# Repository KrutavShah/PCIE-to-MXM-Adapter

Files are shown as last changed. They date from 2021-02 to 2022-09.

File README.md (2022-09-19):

# PCIE to MXM Adapter
This adapter/card allows you to plug an MXM 3.0/3.1 graphics card into a desktop PCI Express port.
There's multiple use cases for this, including MXM card testing, repair, basic computer use, gaming, light workstation use, and more.
This adapter design has been made publicly viewable for educational purposes. 
I made this desicion because of the very high prices that these MXM adapters usually go for online, 
as well as to allow the general public to understand how MXM cards can be interfaced 
with computers to function.
As always, feel free to create issues on this repository and contribute to the project.

Picture of the PCIE x1 to MXM Adapter.

## Current Progress

**Early Prototype:**

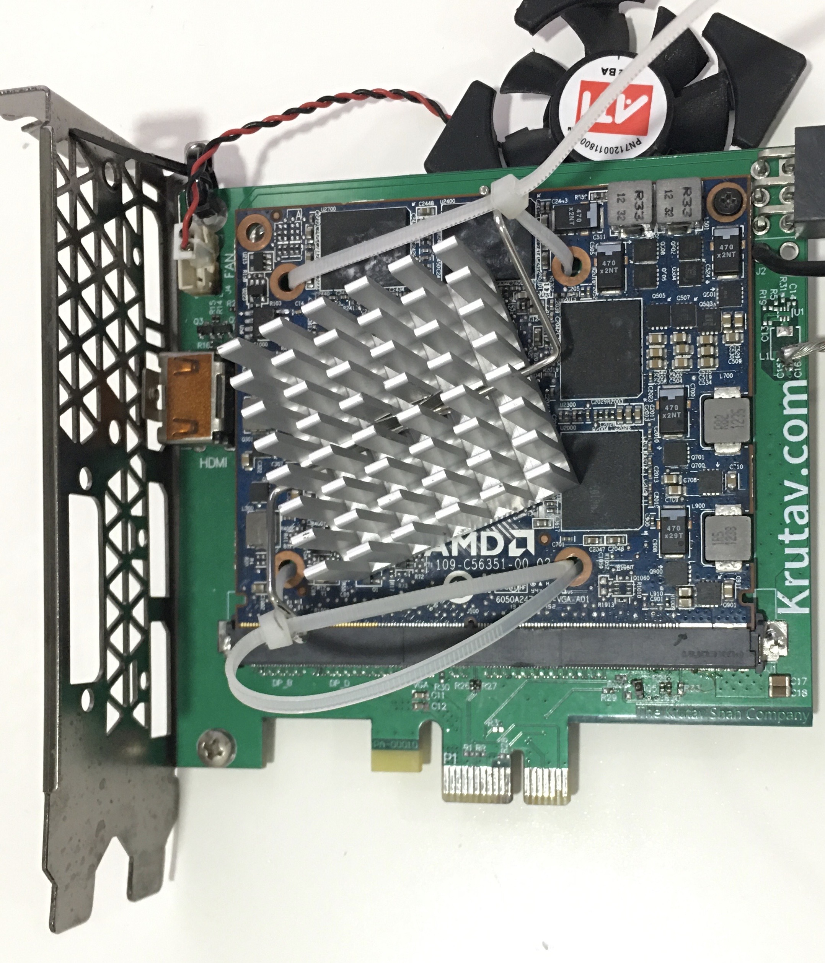
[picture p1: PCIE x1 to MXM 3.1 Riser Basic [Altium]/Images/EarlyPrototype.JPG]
Picture of an early prototype.


What Works:

- HDMI port can output, only version 1.4 bandwidths were tested.
- PCI-e Gen 2 link speed.
- MXM Type-A card fully functional on PCI-e x1 slot power.
- Boot screen and BIOS are accessible through it.
- Can play games and use workstation software.

What Might Not Work:

- PWM fan speed, this feature is dependent on the MXM card's manufacturer including support for it.
- HDMI may show up as a DVI port on some combination of cards and monitors. Further testing will be necessary.

Other features have not been tested due to a lack of MXM cards to test with, such as HDMI Version 2.0 bandwidth. I only have one card, the AMD FirePro M4000, which is an old card and not the best candidate for testing.

**Note:** this is the first prototype and much has changed since it was produced.

## Licensing information
The work of this project is property of Krutav Shah, &copy; 2022. 
Reproduction is not allowed. Commercial use is prohibited.

Some of the material here, such as the footprints in the parts library are the works of various providers such as Molex LLC. Those organizations hold the rights to those resources that have been used in this project.

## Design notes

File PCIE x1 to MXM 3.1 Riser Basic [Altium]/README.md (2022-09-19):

# PCIE x1 to MXM 3.0 Adapter

This adapter card is the most basic one, and includes one HDMI output.
This card is designed to be compact and takes up 100x100mm for inexpensive
PCB fabrication. It has a total of one PCI-e lane and contains basic features.

## What can I use this for?

This card is cheap and small, making it great for testing out and flashing MXM Video Cards.
You can also use it as a video adapter in a machine that needs one, like a server or theater PC.
This card will fit in a full height slot, but not a half height slot.

## Technical Specification

- MXM Type: Version 3 Type A card (Size B may work but there may not be enough power)
- HDMI: 1 Type A port (Should support up to HDMI 2.0)
- Power: Maximum of 25W over PCIE connector as per specification, but actual maximum value may be more or less depending on the motherboard.
- PCB: 4 Layer, 1.6mm Thick, 100x100mm in size. (For JLCPCB Fabrication, use Stackup JLC-2313)

## Help out the project!

Have any issues, comments, or concerns? 
Feel free to create a new issue on GitHub and we can take a look at it.
This product was made in KiCAD EDA originally, but has since moved to Altium Designer.
This project is open source, so contributions are welcome!

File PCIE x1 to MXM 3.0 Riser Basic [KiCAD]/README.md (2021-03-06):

# PCIE x1 to MXM 3.0 Adapter

This adapter card is the most basic one, and includes (1) HDMI output, 
a VGA dummy toggle, and an external 6 pin power connector.
This card is designed to be compact and fit within 100x100mm for inexpensive
PCB fabrication. It has a total of (1) PCIE lane and contains basic features.

## What can I use this for?

This card is cheap and small, making it great for testing out and flashing MXM Video Cards.
You can also use it as a video adapter in a machine that needs one, like a server or theater PC.
This card will fit in a full height slot, but not half height.

## Technical Specification

- MXM Type: 3.0 Type A card (Size B may work with the addition of an external power connector.
- HDMI: 1 Type A port (1.4 compatible)
- VGA: 1 virtual dummy adapter. Turn the dummy toggle to the ON position to activate.
- Power: Maximum of 25W over PCIE connector, but actual maximum value may be less. 
6-Pin power connector is available to increase maximum power throughput.
- PCB: 2 Layer, 1.6mm Thick, Fits within 100x100mm size.

## Help out the project!

Have any issues, comments, or concerns? 
Feel free to create a new issue on GitHub and we can take a look at it.
This whole assembly was made in KiCAD EDA, a free and open source tool.
All of these projects are open source, so contributions are welcome!

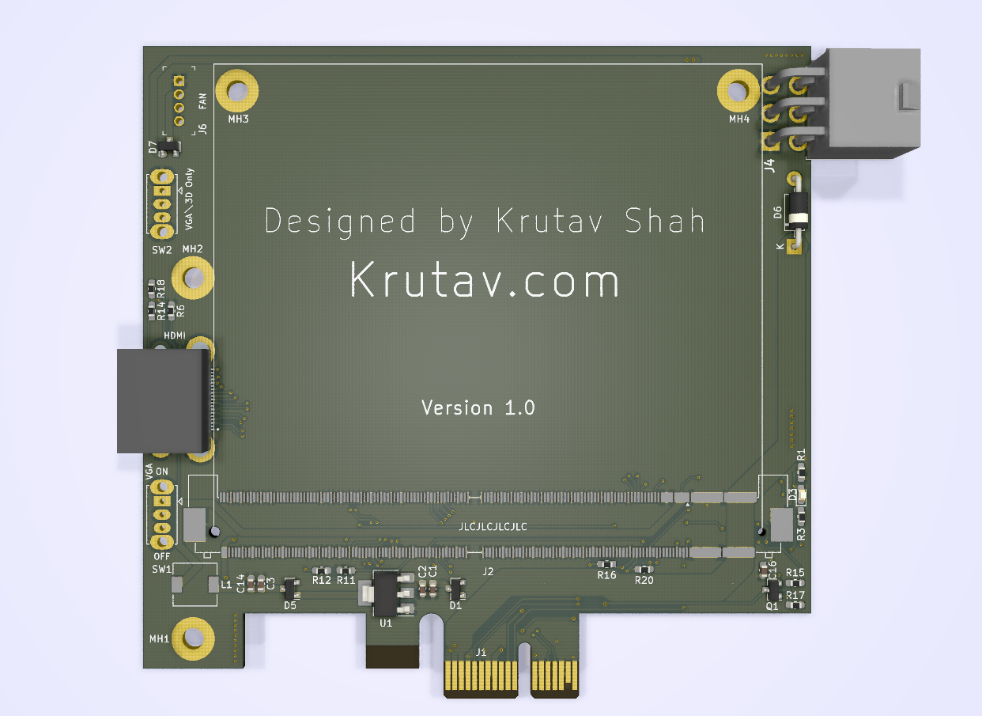
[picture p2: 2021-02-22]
PCIE x1 to MXM 3.0 Riser Basic [KiCAD]/Images/Front1.PNG

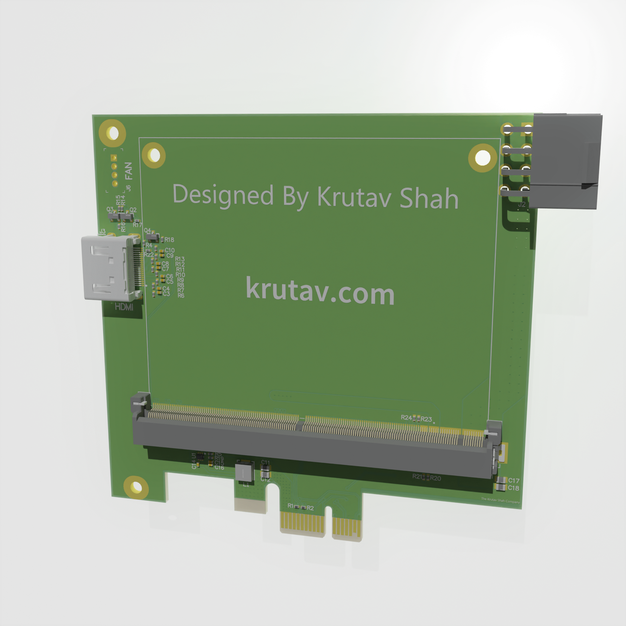
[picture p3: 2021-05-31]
PCIE x1 to MXM 3.1 Riser Basic [Altium]/Images/MXMRiserBasicRender1.png

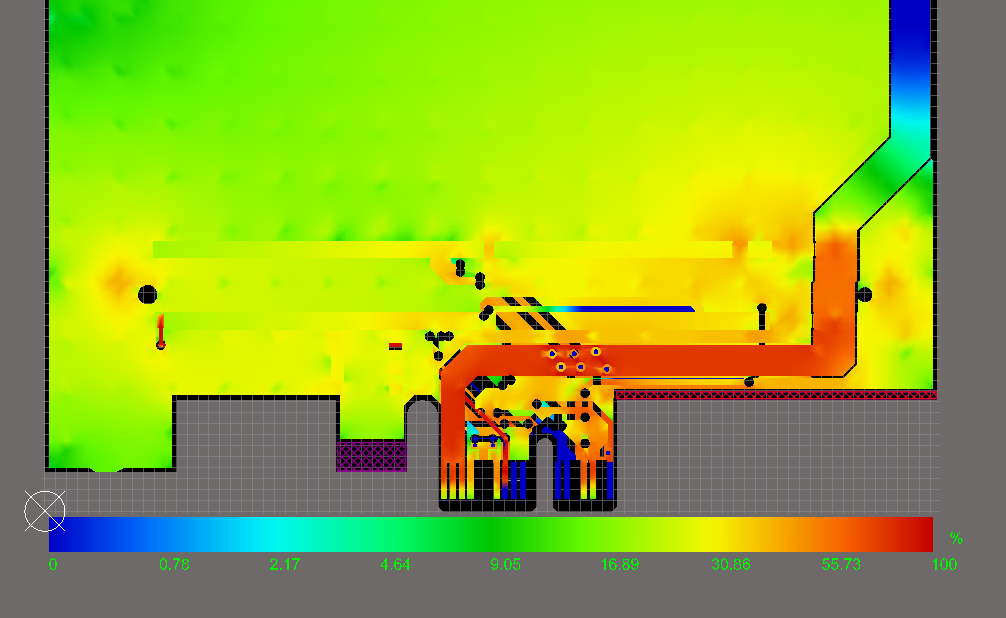
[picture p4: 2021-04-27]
PCIE x1 to MXM 3.1 Riser Basic [Altium]/Images/PDNSimulation.PNG

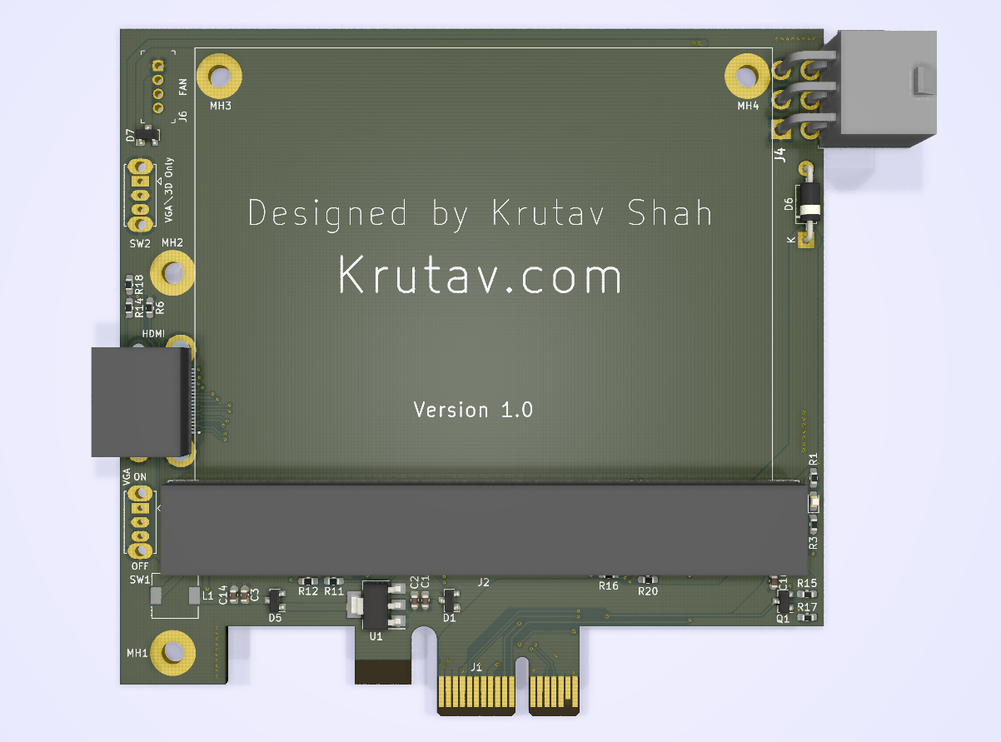
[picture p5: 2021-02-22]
PCIE x1 to MXM 3.0 Riser Basic [KiCAD]/Images/Front2.PNG

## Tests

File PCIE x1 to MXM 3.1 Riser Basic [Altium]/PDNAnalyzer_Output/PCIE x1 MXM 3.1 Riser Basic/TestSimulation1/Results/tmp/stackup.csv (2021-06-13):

layername
TOPSOLDER
TOPLAYER
SUBSTRATE-1
INTERNALPLANE1
SUBSTRATE-2
INTERNALPLANE2
SUBSTRATE-3
BOTTOMLAYER
BOTTOMSOLDER

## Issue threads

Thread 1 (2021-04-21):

Adapter design discussion

chraac, 2021-04-21:
Looks the PCB files in altium project of both x1 and x16 was not properly updated, are they still under development?

chraac, 2021-04-21:
Also the Altium Designer show that the footprint of PCIeX1 was not found, just curious if it missing something when convert from KiCAD project

KrutavShah, 2021-04-21:
Yes, it is still under development. Currently I am working on other projects so time is limited.

The goal is to transition from KiCAD to Altium, so I’m in the process of redesigning each board in Altium to gain more advanced features necessary for designing the board with high speed signals and relatively good design standards.

chraac, 2021-04-21:
> Yes, it is still under development. Currently I am working on other projects so time is limited.
>
> The goal is to transition from KiCAD to Altium, so I’m in the process of redesigning each board in Altium to gain more advanced features necessary for designing the board with high speed signals and relatively good design standards.

Thanks for quick reply, I think I can help to do some developing or testing, I have a spare MXM graphics card and can test the PCB if it work.

KrutavShah, 2021-04-21:
Thanks for the offer, I do have an MXM card available too, so the only issue is that it will take a few weeks to actually manufacture the adapter.

Since the project is still in development, it will take some time before its fully ready for manufacturing. If you want to help contribute to designing and/or validation, feel free to do so!

chraac, 2021-04-25:
@KrutavShah, anyway, I think you should remove the ```History``` folder under every altium project, it's altium zip cache, unable to diff by version control. Or init the [Git LFS](https://git-lfs.github.com/) to manage it more efficiently.

KrutavShah, 2021-04-25:
I will add .zip files to the gitignore in that case, thanks for the suggestion. I hope to commit the work I have been working on for the past few days to this repository today.

chraac, 2021-04-26:
From the [MXM spec v3.1, page 36](https://www.module-store.de/media/pdf/d9/a4/43/MXM_Specification_v31_r10.pdf), the ```PWR_LEVEL``` pin define 1 as full power, and should pull-up to 3.3v with 100KΩ resistor, I think we should follow the spec.

KrutavShah, 2021-04-26:
So the last commit that I made yesterday was simply to route PCIE. Stitching vias and MXM specific pull up and pull down resistors will come next in the next few days. I have all the MXM design papers except for the MXM System Design Guide which is perhaps the most useful.

The things that I’m not sure about how to implement is actually the PWR_EN and TH_OVERT# signals. There may also be some more signals to consider later on that I’m not entirely sure on. For example, newer cards don’t support TMDS/LVDS which means HDMI needs to be connected to DisplayPort.

chraac, 2021-04-27:
I think it will be relative easy if we only implement the ```PWR_EN```, from the spec, we can pull-up the ```PWR_EN``` when all 12v/5v/3.3v are ready, and then the module will give us a ```PWR_GOOD``` within 90ms to enable the signal input.
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

And the ```TH_OVERT#``` is for over heat shutdown, IMHO, maybe we can just pull-up to 3.3v, leave it for later implementation since we are not on a budget of cooler.

KrutavShah, 2021-04-27:
> from the spec, we can pull-up the PWR_EN when all 12v/5v/3.3v are ready

But how would you? The idea I had previously is to branch PWR_EN off +5V with a voltage divider (2 resistors) and the reason being that 5V is created the last, and then using the resistor divider turns the 5V into 3.3V. IIRC, PWR_GOOD is not a required signal and can therefore be omitted.

> And the TH_OVERT# is for over heat shutdown, IMHO, maybe we can just pull-up to 3.3v

We actually should keep TH_OVERT# because it's a required signal, and while the adapters are supposed to be cheap, I would not remove this important feature just to save a fraction of a dollar. So how do we implement this? One possible solution is with a transistor. If TH_OVERT# is asserted, the transistor will open and send 3.3V directly to PCIE_RESET#. Let me know if this will work, or if you have any comments on the solution.

chraac, 2021-05-03:
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

Use 2 resistor as voltage divider should be ok since the resistance of PWR_EN to GND is far more bigger than our resistor's. But I had to go to PCIR spec to find which one of 12/5/3.3 come first.

KrutavShah, 2021-05-03:
> Use 2 resistor as voltage divider should be ok since the resistance of PWR_EN to GND is far more bigger than our resistor's. But I had to go to PCIR spec to find which one of 12/5/3.3 come first.

This is already in the KiCAD design file and will be added to the Altium file when I have time. What I don't understand is how much 5V current is actually needed. MXM specifications says 2.5 Amps is required, but the AMS1117 can only provide 1 Amp. There are buck converters on the market capable of 3 Amps, but they are from companies like Anpec which don't sell on DigiKey or Mouser. I did find one of them on LCSC for $2 but it will take a long time to ship here.

In addition, I need to know how TH_OVERT# will be implemented because it has to assert a PCIE Reset, but how is not known.

chraac, 2021-05-04:
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

I did find a 12v to 5v buck converter from TI website - [LM2596 SIMPLE SWITCHER® Power Converter 150-kHz
3-A Step-Down Voltage Regulator](https://www.ti.com/lit/ds/symlink/lm2596.pdf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), and the example circuit look very simple:
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
Just 2 capacitor, 1 diode and 1 inductor, no extra MOSFET, it's fully integrated.

KrutavShah, 2021-05-04:
The LM2596 is huge, and making space for it on such a small board doesn't make as much sense. There are 3A 5V converters like those from Anpec and uPI Group that fit in a very small SOP-8 package and are designed to be used in these electronics. Though they are not sold on sites like DigiKey, so I have to find a good similar alternative.

chraac, 2021-05-07:
> The LM2596 is huge, and making space for it on such a small board doesn't make as much sense. There are 3A 5V converters like those from Anpec and uPI Group that fit in a very small SOP-8 package and are designed to be used in these electronics. Though they are not sold on sites like DigiKey, so I have to find a good similar alternative.

I think 1 amp from AMS1117 is not sufficient for recent GPU, I also doubt that the SOP-8 buck convertor is can provide up to 3 amps output. I gonna find another solution for 12v to 5v on DigiKey.

KrutavShah, 2021-05-07:
Actually, in addition to the 2.5 Amps for the GPU MXM card, you will notice on most normal desktop graphics cards that there is a separate AMS1117-5.0 just for powering the HDMI and DVI ports. Since we are using a 3A buck converter, that may be able to spare some current for the display outputs.

https://fscdn.rohm.com/en/products/databook/datasheet/ic/power/switching_regulator/bd9d321efj-e.pdf
Take a look at this one I have found for a reasonable price.

chraac, 2021-05-08:
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

Good to see a sop8 convertor solution for 12v to 5v in such small package. I know that the recent desktop graphic card rely on 12v far more than 5v for supplying GPU and MEM, but, IMHO, the mobile gpu may different since the battery maybe less than 12v, and the peripherals may using 5v usually than 12v（fan and others）.

KrutavShah, 2021-05-08:
>I know that the recent desktop graphic card rely on 12v far more than 5v for supplying GPU and MEM, but, IMHO, the mobile gpu may different since the battery maybe less than 12v, and the peripherals may using 5v usually than 12v(fan and others).

There's a lot more under the hood when it comes to desktop GPUs, as they usually have multiple 5V sources and possibly even multiple 3.3V sources according to the schematics. As far as MXM is concerned, 2.5A should be enough to drive the GPU power controller, clock, and a couple other components. Each HDMI port needs about 50-60 mA @ 5V, and DisplayPort uses 3.3V@500 mA.

In the case of this basic design, 3 Amps will be just fine. There is a difference between switching buck converters/voltage regulators and LDOs, as the more common switching chips used here need external circuitry like an inductor, capacitors, and resistors. LDOs (Low dropout regulators) don't need nearly as many extra passive components IIRC, so I am trying to find one of those instead.

I've worked on the design a fair bit, but I can't push it yet until the schematics are corrected, so I hope to get that done soon.

KrutavShah, 2021-05-08:
Moved to the discussions tab.

Closed 2021-05-08.

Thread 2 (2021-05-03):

For purchase anywhere?

nmjohnson, 2021-05-03:
Are you or any vendor making these?

KrutavShah, 2021-05-03:
The design is not complete yet, and is not ready for manufacture.

The goal is to make it so the PCB will only cost a few dollars, or in other words, be very low-cost. It's only for personal use, not commercial, which is why this open-source design is provided to the consumer only for the purpose of finding a manufacturing service to manufacture one of these for personal use.

JLCPCB offers PCB fabrication for a really low cost, so that may be a service you might consider using when going to get this design fabricated.

nmjohnson, 2021-05-03:
I understand. Well whenever it's ready I would like to test it out so let me know!

Tretecou, 2022-02-04:
Hey there, I would like to ask if the current design supports a graphics card that can draw up to 90W - such as the tesla p6.
Thanks in advance!

Tretecou, 2022-02-05:
>

Thanks a lot! I will be waiting for it - one more question, whats the best place and way to learn electronics engineering, electronics repair on a semi professional level without actually attending a dedicated school for this topic? Since im pretty young to actually go to a school like this and ive also missed my opportunity to visit a low level engineering school, are there other ways? I sometimes cant find enough time or get easily distracted when learning something. Plus i dont know what to learn exactly, ive missed a lot of beginner knowledge by not going to the type of school.
Thanks a lot for any kind of answer!
Happy designing :D

KrutavShah, 2022-07-13:
> Thanks a lot! I will be waiting for it - one more question, whats the best place and way to learn electronics engineering, electronics repair on a semi professional level without actually attending a dedicated school for this topic? Since im pretty young to actually go to a school like this and ive also missed my opportunity to visit a low level engineering school, are there other ways? I sometimes cant find enough time or get easily distracted when learning something. Plus i dont know what to learn exactly, ive missed a lot of beginner knowledge by not going to the type of school.
> Thanks a lot for any kind of answer!
> Happy designing :D

Hi, I apologize for not responding. If you’re still interested, I actually started this project without much knowledge of electronics design. Essentially, I had an idea, and knowledge of electronics repair and some of the basic concepts. The idea for this project came up when I had an MXM GPU but no way to actually use it. I want to emphasize that this project was not easy by any means, and I learned a lot just by doing. Concepts like signal integrity become especially important when dealing with high speed signals, so for issues like these, I read articles and watched videos that show proper practices and how to use tools within the design software to achieve the desired result. This project was started over a year ago and has experienced many major revisions as I made important realizations with each one.

I’m glad to hear that you’re interested in learning electronics, and you too can certainly begin the journey of learning how to design your own electronics products as you go. It won’t be particularly easy, but you’ll learn more with each revision and gain important experience. My best advice is to come up with what you want to make, making sure that your idea is still feasible. Once you have an idea in mind, you can draw it out, write about it, and begin your research. If you’ve made it to that point, you can begin designing in various different CAD software like KiCAD.

Hope this helps you, and thank you for asking!

Tretecou, 2022-07-13:
no biggie

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

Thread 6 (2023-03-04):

PCIe x16 version

renne, 2023-03-04:
This is a great project! :+1:

PCIe x1 is quite a bottleneck for modern GPUs.
I suggest to upgrade the PCB to PCIe x16 like the [EGX-MXM-AD](https://www.adlinktech.com/Products/Embedded_Graphics/embedded-graphics-solutions/EGX-MXM-AD?lang=en) or the [Eurocom](https://eurocom.com/ec/multigpu()multiGPU) riser cards.

KrutavShah, 2023-03-04:
I agree, x1 is definitely a bottleneck from my testing. I do have an x16 design that is missing a few components here and there, so not complete, but I have not released that here because I feel like the interest in this project has fallen away after a while of not being updated.

If this x16 version (with 4x DisplayPorts) is something you still want to see, I would be inclined against adding all the design files here, simply because the ones for x1 design already available here have been copied by others without credit. I feel like it may not be worth bothering with as a result. I am, however, open to considering this again in the future if there is enough interest. Here is what the design currently looks like:
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

renne, 2023-03-05:
Great! :+1:
Please make sure the positions of the video ports match an easily available bezel.
It would also be great to have an universal PCB layout which allows to solder HDMI or Displayport sockets at will.

KrutavShah, 2023-03-05:
The PCB layout matches Nvidia's 10/20 series PCI brackets, so you could get one of those and the ports should line up exactly. On the front page of this repository, I have one of these GTX 1060 brackets installed on my prototype which you take a look at if you'd like. Quadro brackets should also work. I do not think AMD brackets line up with the ports, though.

RansomScientist, 2023-03-12:
> I agree, x1 is definitely a bottleneck from my testing. I do have an x16 design that is missing a few components here and there, so not complete, but I have not released that here because I feel like the interest in this project has fallen away after a while of not being updated.
>
> If this x16 version (with 4x DisplayPorts/3x DP + 1x HDMI) is something you still want to see, I would be inclined against adding all the design files here, simply because the ones for x1 design already available here have been copied by others without credit. I feel like it may not be worth bothering with as a result. I am, however, open to considering this again in the future if there is enough interest. Here is what the design currently looks like: 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

Hey, thank you very much for your design, what intrigues me though is if you have considered trace pair impedance and length matching? With 1x it might not be too much of a problem but with 16x I'm guessing it would be extremely important but I can't see any of that in the image?

KrutavShah, 2023-03-12:
> Hey, thank you very much for your design, what intrigues me though is if you have considered trace pair impedance and length matching? With 1x it might not be too much of a problem but with 16x I'm guessing it would be extremely important but I can't see any of that in the image?

Yes, the impedance of the differential pairs has been set in the PCB editor to meet a target of around 85 ohms, the standard for PCIe gen 3. As for the length matching, individual traces within pairs will be matched, but the inter-pair skew has some room for variation, which is why the separate lanes themselves are not matched. This shouldn't be much of an issue here. The goal here is to keep the lengths of the pairs short to minimize unnecessary losses.

This is from a Texas Instruments PCIe Layout Guidelines document:
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

RansomScientist, 2023-03-12:
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

Good to know, if the design ever gets published or you feel comfortable sharing it in private it would be really nice if you could let me know. I would also happily share tests results if I build one.

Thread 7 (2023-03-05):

HDMI-CEC support

renne, 2023-03-05:
As commercial GPUs usually lack HDMI-CEC support it would be great to add an [HDMI-CEC-to-serial](https://os.mbed.com/users/WiredHome/notebook/hdmi-cec-interface/) adapter to the PCIE-to-MXM-Adapter.

KrutavShah, 2023-03-05:
I could add a CEC header, similar to Intel NUCs, as that will allow users can wire the CEC port to a microcontroller that can use CEC for external functions. I have not seen any graphics cards that implement CEC, even though the MXM port does have a CEC input pin.

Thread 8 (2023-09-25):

improvements

Paduo-KoTuK, 2023-09-25:
It would be nice to rotate the video card 90 degrees and make a separate thermal sensor for old cards.  And is it possible to add an LVDS output here?  And yes, everything was translated through Google translator.

Paduo-KoTuK, 2023-09-25:
And additional power for new and demanding video cards.

KrutavShah, 2023-09-25:
Hi, unfortunately, this project is no longer being worked on by me. If you'd like, you can download the files and make any adjustments you'd like before ordering.

Paduo-KoTuK, 2023-09-25:
Sorry, why was the project abandoned?  I think the topic is interesting and can be continued :)

Paduo-KoTuK, 2023-09-25:
Could you also attach the gerber file, there is no way to get it.

Paduo-KoTuK, 2023-09-25:
both pci-e 16x and 1x please.

Demopans, 2024-04-25:
for any future people interested, I have found a different project by someone who showed up in my feed. This appears to be a bit more active

https://github.com/a-little-wifi/mxm-immobilizer

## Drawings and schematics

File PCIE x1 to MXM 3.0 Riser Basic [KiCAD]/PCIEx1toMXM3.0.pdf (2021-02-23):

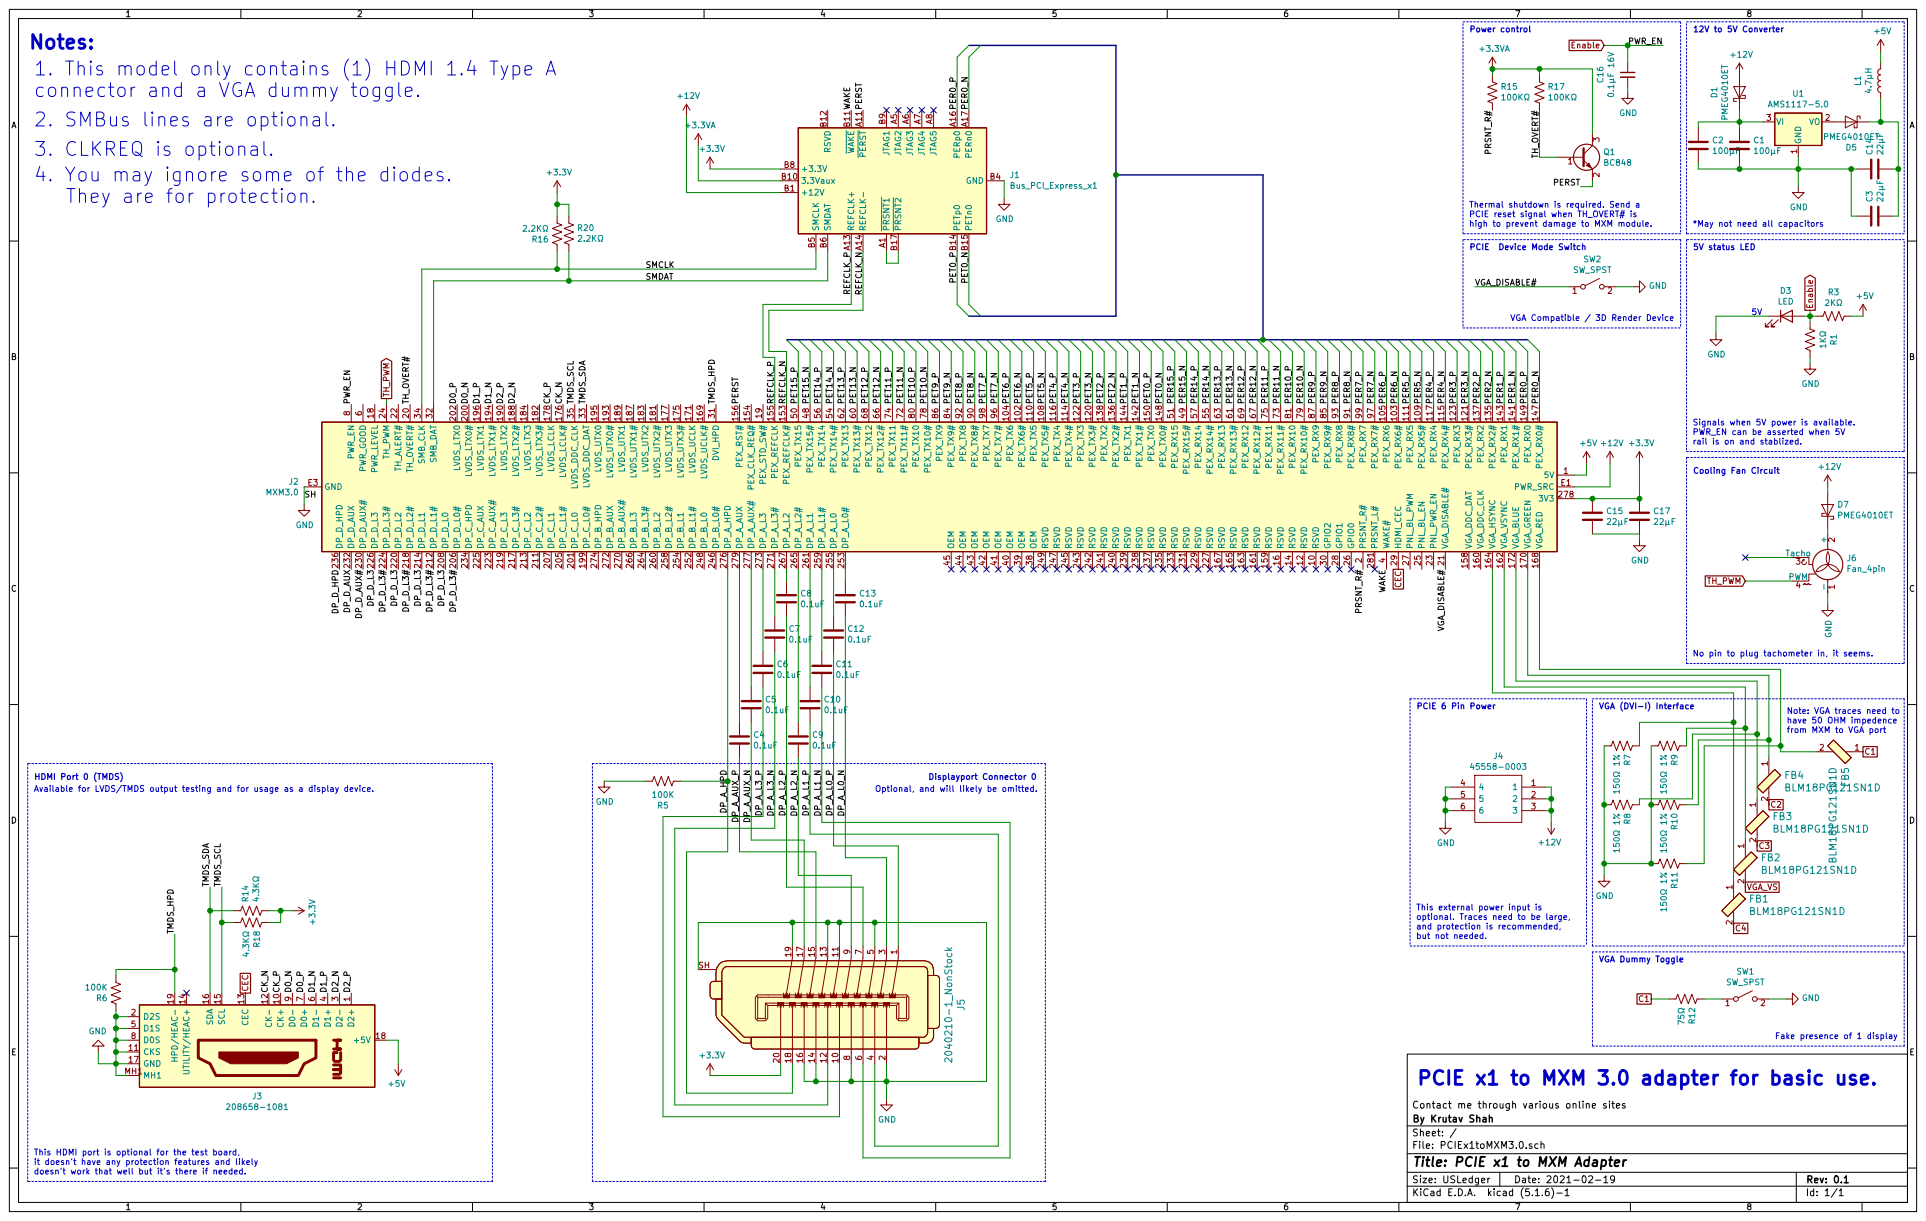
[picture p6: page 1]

5V status LED Notes:
1. This model only contains (1) HDMI 1.4 Type A

12V to 5V Converter Signals when 5V power is available. PWR_EN can be asserted when 5V
+12V +3.3V C16 0.1F 16V GND
D5 PMEG4010ET D7PMEG4010ET D1 PMEG4010ET

2. SMBus lines are optional.
3. CLKREQ is optional.
4. You may ignore some of the diodes.
They are for protection.

Thermal shutdown is required. Send a
PCIE reset signal when TH_OVERT# is
high to prevent damage to MXM module.

*May not need all capacitors

VGA Compatible / 3D Render Device

2 TH_OVERT# 20 LVDS_LTX0# 200 DP_C_L0 201 LVDS_LTX0 202 DP_C_L1# 205 DP_D_L0# 206 DP_C_L1 207 DP_D_L0 208 VGA_DISABLE# 21 DP_C_L2# 211 DP_D_L1# 212 DP_C_L2 213 DP_D_L1 214 DP_C_L3# 217 DP_D_L2# 218 DP_C_L3 219 TH_ALERT# 22 DP_D_L2 220 DP_C_AUX# 223 DP_D_L3# 224 DP_C_AUX 225 DP_D_L3 226 RSVD 227 RSVD 229 PNL_PWR_EN 23 DP_D_AUX# 230 RSVD 231 DP_D_AUX 232 RSVD 233 DP_C_HPD 234 RSVD 235 DP_D_HPD 236 RSVD 237 RSVD 238 RSVD 239 TH_PWM 24 RSVD 240 RSVD 241 RSVD 242 RSVD 243 RSVD 245 DP_B_L0# 246 RSVD 247 DP_B_L0 248 RSVD 249 PNL_BL_EN 25 DP_B_L1# 252 DP_A_L0# 253 DP_B_L1 254 DP_A_L0 255 DP_B_L2# 258 DP_A_L1# 259 GPIO0 26 DP_B_L2 260 DP_A_L1 261 DP_B_L3# 264 DP_A_L2# 265 DP_B_L3 266 DP_A_L2 267 PNL_BL_PWM 27 DP_B_AUX# 270 DP_A_L3# 271 DP_B_AUX 272 DP_A_L3 273 DP_B_HPD 274 DP_A_HPD 276 DP_A_AUX# 277

4 OEM 40 OEM 41 OEM 42 OEM 43 OEM 44 OEM 45 PEX_TX15# 48 PEX_RX15# 49 PEX_TX15 50 PEX_RX15 51 PEX_TX14# 54 PEX_RX14# 55 PEX_TX14 56 PEX_RX14 57 PWR_GOOD

rail is on and stablized. Cooling Fan Circuit
and protection is recommended, but not needed. PCIE 6 Pin Power

No pin to plug tachometer in, it seems.

from MXM to VGA port

This external power input is
optional. Traces need to be large,

1 CK+ 10 CKS 11 CK- 12 CEC 13 UTILITY/HEAC+ 14 SCL 15 SDA 16 GND 17 +5V 18 HPD/HEAC- 19 D2S 2 D2- 3 D1+

Fake presence of 1 display

Contact me through various online sites
Id: 1/1 Title: PCIE x1 to MXM Adapter File: PCIEx1toMXM3.0.sch Sheet: / By Krutav Shah

This HDMI port is optional for the test board,

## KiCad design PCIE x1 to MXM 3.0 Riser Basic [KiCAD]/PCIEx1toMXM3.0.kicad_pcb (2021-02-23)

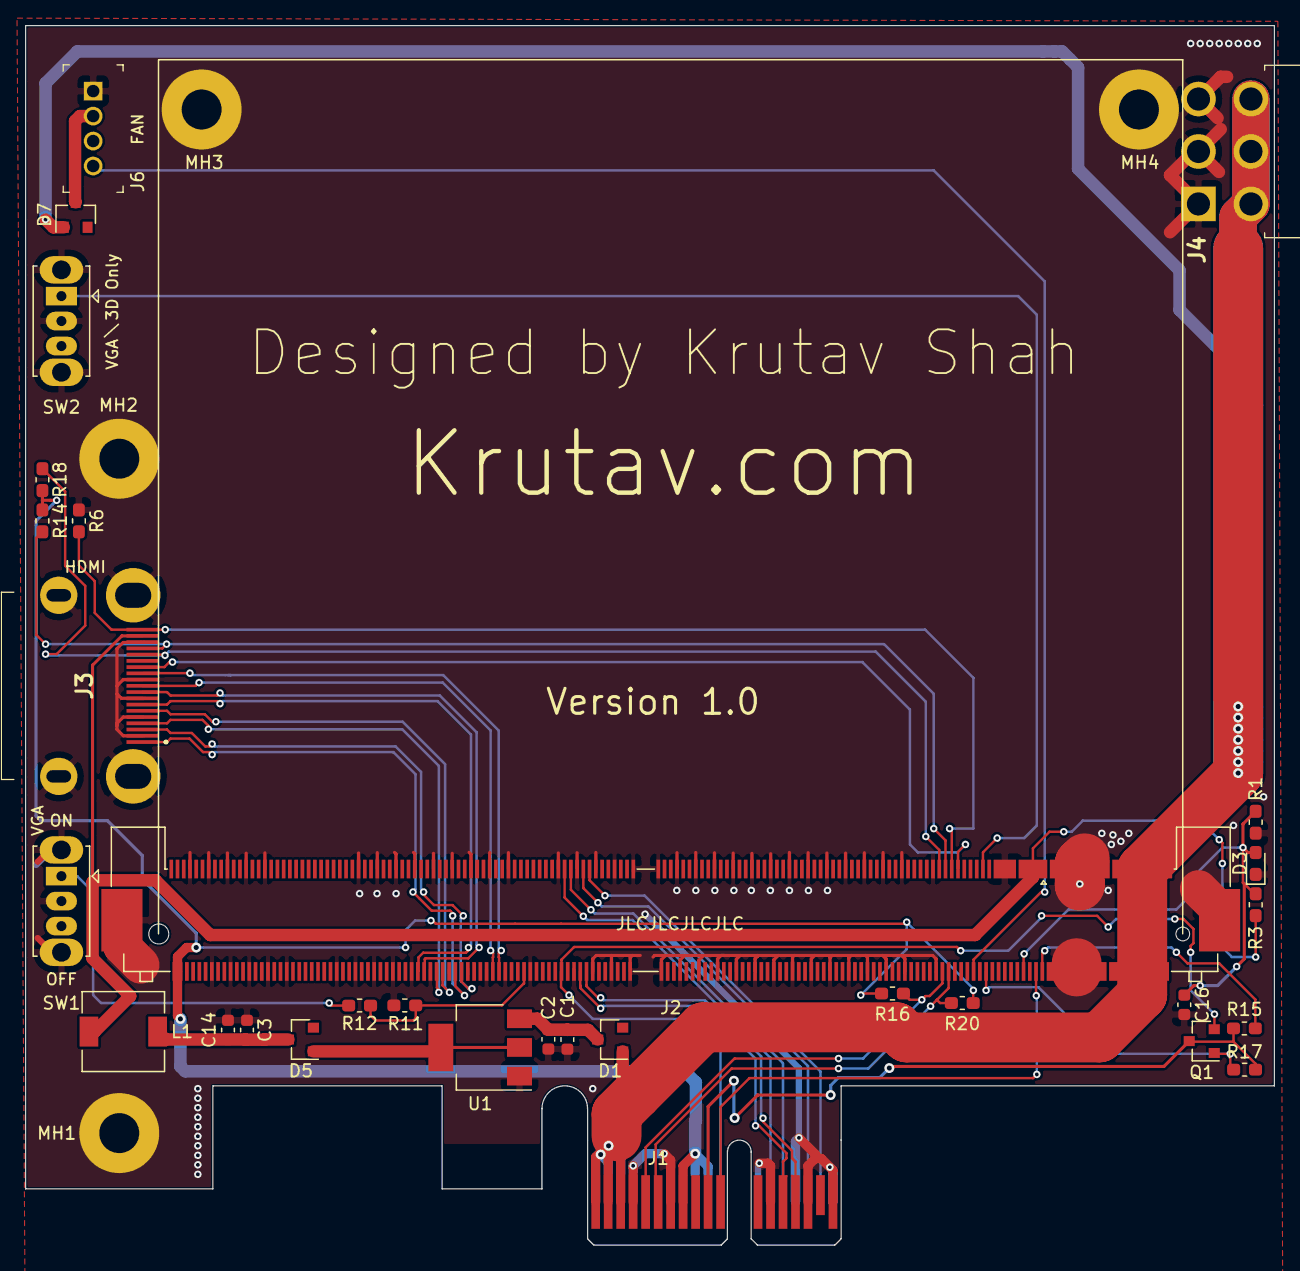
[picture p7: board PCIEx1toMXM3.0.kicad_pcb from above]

Board: 2 copper layers, 100.0 x 97.7 mm, 34 parts (0 on the bottom side), 39 nets.

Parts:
C1, C2, C3, C14, C16: C_0603_1608Metric
D1, D5, D7: PMEG4010ET; D_SOT-23_ANK
D3: LED_0603_1608Metric_Pad1.05x0.95mm_HandSolder
J1: Bus_PCI_Express_x1; BUS_PCIexpress_x1
J2: MXM3.0; JAE_MM70-314-310B1
J3: 208658-1081; 2086581081
J4: 45558-0003; 455580003
J6: PinHeader_1x4_P2mm_Drill1mm
L1: L_6.3x6.3_H3
MH1, MH2, MH3, MH4: MountingHole_3.2mm_M3_Pad
Q1: BC848; SOT-23
R1, R3, R6, R11, R12, R14, R15, R16, R17, R18, R20: R_0603_1608Metric_Pad1.05x0.95mm_HandSolder
SW1, SW2: SW_Slide_1P2T_CK_OS102011MS2Q
U1: AMS1117-5.0; SOT-223-3_TabPin2

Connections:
+3.3VA: J1.B10, Q1.3, R15.2, R17.2
+3V3: J1.A9, J1.A10, J1.B8, J2.278, J2.280, R14.1, R16.1, R18.2, R20.2
+5V: C3.2, C14.2, J2.1, J2.3, J2.5, J2.7, J2.9, J3.18, L1.1, L1.2, R3.1
+12V: D1.2, D7.2, J1.A2, J1.A3, J1.B1, J1.B2, J1.B3, J2.E1, J2.E2, J4.1, J4.2, J4.3
/CK_N: J2.176, J3.12
/CK_P: J2.178, J3.10
/D0_N: J2.200, J3.9
/D0_P: J2.202, J3.7
/D1_N: J2.194, J3.6
/D1_P: J2.196, J3.4
/D2_N: J2.188, J3.3
/D2_P: J2.190, J3.1
/DP_D_L3: J2.208, J2.214, J2.220, J2.226
/DP_D_L3#: J2.206, J2.212, J2.218, J2.224
/PER0_N: J1.A17, J2.147
/PER0_P: J1.A16, J2.149
/PERST: J1.A11, J2.156, Q1.2
/PET0_N: J1.B15, J2.148
/PET0_P: J1.B14, J2.150
/PRSNT_R#: J2.2, R15.1
/REFCLK_N: J1.A14, J2.153
/REFCLK_P: J1.A13, J2.155
/SMCLK: J1.B5, J2.34, R16.2
/SMDAT: J1.B6, J2.32, R20.1
/TH_OVERT#: J2.20, Q1.1, R17.1
/TMDS_HPD: J2.31, J3.19, R6.2
/TMDS_SCL: J2.35, J3.15, R18.1
/TMDS_SDA: J2.33, J3.16, R14.2
/VGA_DISABLE#: J2.21, SW2.1
/WAKE: J1.B11, J2.4
CEC: J2.29, J3.13
Enable: C16.1, D3.2, J2.8, R1.2, R3.2
GND: C1.2, C2.2, C3.1, C14.1, C16.2, D3.1, J1.A4, J1.A12, J1.A15, J1.A18, J1.B4, J1.B7, J1.B13, J1.B16, J1.B18, J2.11, J2.13, J2.15, J2.17, J2.36, J2.37, J2.46, J2.47, J2.52, J2.53, J2.58, J2.59, J2.64, J2.65, J2.70, J2.71, J2.76, J2.77, J2.82, J2.83, J2.88, J2.89, J2.94, J2.95, J2.100, J2.101, J2.106, J2.107, J2.112, J2.113, J2.118, J2.119, J2.124, J2.125, J2.133, J2.134, J2.139, J2.140, J2.145, J2.146, J2.151, J2.152, J2.157, J2.166, J2.173, J2.174, J2.179, J2.180, J2.185, J2.186, J2.191, J2.192, J2.197, J2.198, J2.203, J2.204, J2.209, J2.210, J2.215, J2.216, J2.221, J2.222, J2.228, J2.244, J2.250, J2.251, J2.256, J2.257, J2.262, J2.263, J2.268, J2.269, J2.275, J2.E3, J2.E4, J2.MP, J3.2, J3.5, J3.8, J3.11, J3.17, J3.MH1, J3.MH2, J3.MH3, J3.MH4, J4.4, J4.5, J4.6, J6.1, MH1.1, MH2.1, MH3.1, MH4.1, R1.1, R6.1, R11.1, SW1.2, SW2.2, U1.1
unnamed: C1.1, C2.1, D1.1, U1.3
unnamed: D5.2, U1.2
unnamed: D7.1, J6.2
unnamed: J2.168, R11.2, R12.1
unnamed: J1.A1, J1.B17
TH_PWM: J2.24, J6.4

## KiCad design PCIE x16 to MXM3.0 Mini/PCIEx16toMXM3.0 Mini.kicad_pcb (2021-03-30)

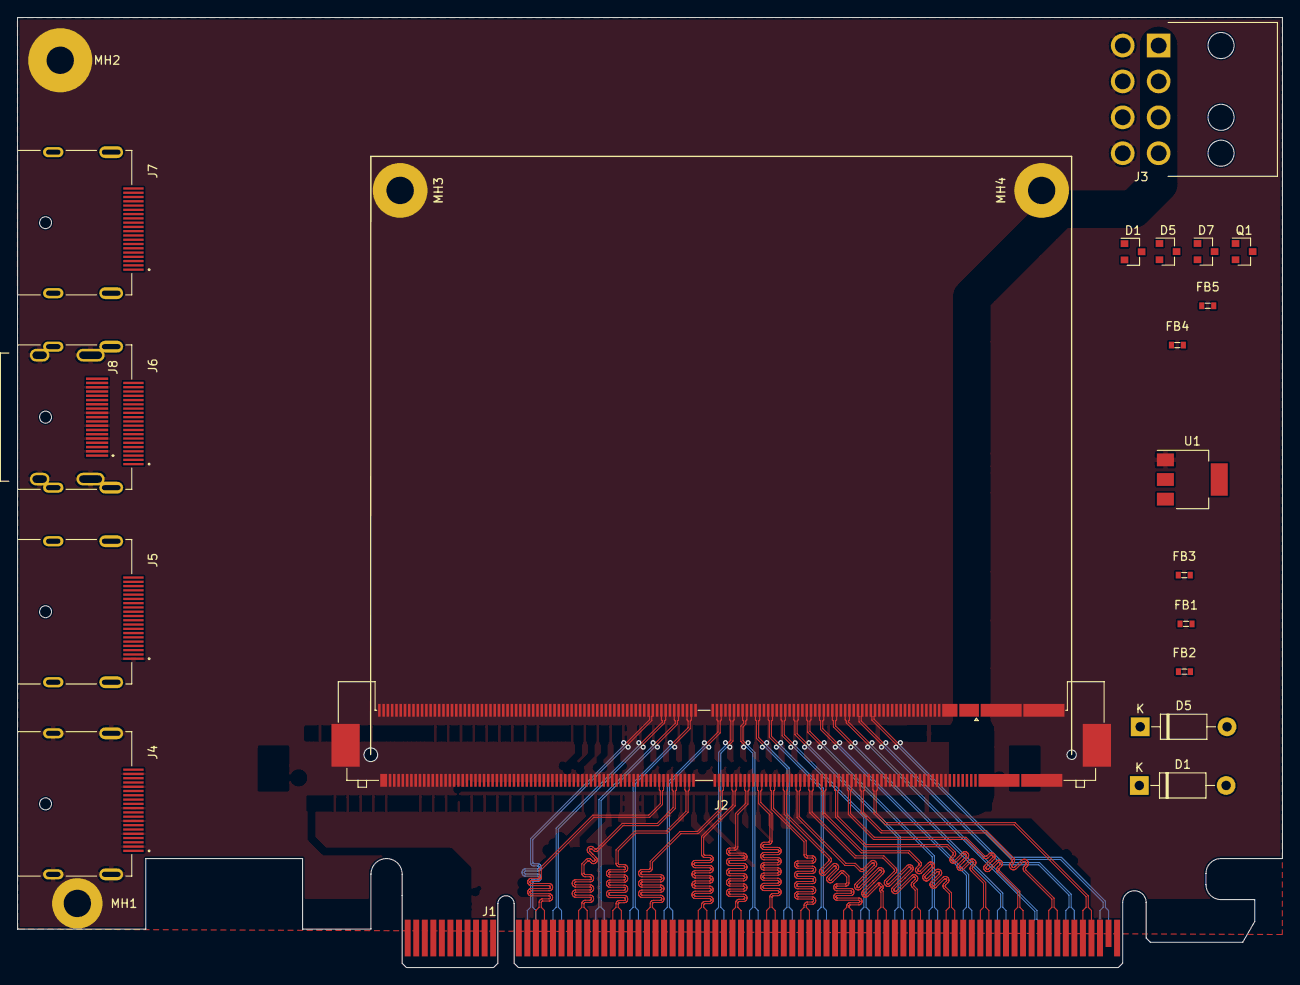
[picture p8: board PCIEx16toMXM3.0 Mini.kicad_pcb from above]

Board: 4 copper layers, 148.0 x 111.2 mm, 24 parts (0 on the bottom side), 102 nets.

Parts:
D1, D5: PMEG4010ET; D_DO-41_SOD81_P10.16mm_Horizontal
D1#2, D5#2, D7: PMEG4010ET; D_SOT-23_ANK
FB1, FB2, FB3, FB4, FB5: BLM18PG121SN1D; 0603
J1: Bus_PCI_Express_x16; BUS_PCIexpress_x16
J2: MXM3.0; JAE_MM70-314-310B1
J3: Molex-45586 8 Pin PWR; Molex_45586-8-Pin-PWR
J4, J5, J6: 47272-0001; MOLEX_47272-0001
J7: MOLEX_47272-0001
J8: 208658-1081; 2086581081
MH1, MH2, MH3, MH4: MountingHole_3.2mm_M3_Pad
Q1: BC848; SOT-23
U1: AMS1117-5.0; SOT-223-3_TabPin2

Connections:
+3.3VA: J1.B10, Q1.3
+3V3: J1.A9, J1.A10, J1.B8, J2.278, J2.280, J4.20
+5V: J2.1, J2.3, J2.5, J2.7, J2.9, J8.18
+12V: D1.2, D1#2.2, D7.2, J1.A2, J1.A3, J1.B1, J1.B2, J1.B3, J2.E1, J2.E2, J3.1, J3.2, J3.3, J3.4
/CK_N: J2.176, J8.12
/CK_P: J2.178, J8.10
/CLKREQ#: J1.B12, J2.154
/D0_N: J2.200, J8.9
/D0_P: J2.202, J8.7
/D1_N: J2.194, J8.6
/D1_P: J2.196, J8.4
/D2_N: J2.188, J8.3
/D2_P: J2.190, J8.1
/DP_A_HPD: J2.273, J2.276, J4.18
/DP_C_HPD: J2.234, J2.274
/PER0_N: J1.A17, J2.147
/PER0_P: J1.A16, J2.149
/PER1_N: J1.A22, J2.141
/PER1_P: J1.A21, J2.143
/PER2_N: J1.A26, J2.135
/PER2_P: J1.A25, J2.137
/PER3_N: J1.A30, J2.121
/PER3_P: J1.A29, J2.123
/PER4_N: J1.A36, J2.115
/PER4_P: J1.A35, J2.117
/PER5_N: J1.A40, J2.109
/PER5_P: J1.A39, J2.111
/PER6_N: J1.A44, J2.103
/PER6_P: J1.A43, J2.105
/PER7_N: J1.A48, J2.97
/PER7_P: J1.A47, J2.99
/PER8_N: J1.A53, J2.91
/PER8_P: J1.A52, J2.93
/PER9_N: J1.A57, J2.85
/PER9_P: J1.A56, J2.87
/PER10_N: J1.A61, J2.79
/PER10_P: J1.A60, J2.81
/PER11_N: J1.A65, J2.73
/PER11_P: J1.A64, J2.75
/PER12_N: J1.A69, J2.67
/PER12_P: J1.A68, J2.69
/PER13_N: J1.A73, J2.61
/PER13_P: J1.A72, J2.63
/PER14_N: J1.A77, J2.55
/PER14_P: J1.A76, J2.57
/PER15_N: J1.A81, J2.49
/PER15_P: J1.A80, J2.51
/PERST: J1.A11, J2.156, Q1.2
/PET0_N: J1.B15, J2.148
/PET0_P: J1.B14, J2.150
/PET1_N: J1.B20, J2.142
/PET1_P: J1.B19, J2.144
/PET2_N: J1.B24, J2.136
/PET2_P: J1.B23, J2.138
/PET3_N: J1.B28, J2.120
/PET3_P: J1.B27, J2.122
/PET4_N: J1.B34, J2.114
/PET4_P: J1.B33, J2.116
/PET5_N: J1.B38, J2.108
/PET5_P: J1.B37, J2.110
/PET6_N: J1.B42, J2.102
/PET6_P: J1.B41, J2.104
/PET7_N: J1.B46, J2.96
/PET7_P: J1.B45, J2.98
/PET8_N: J1.B51, J2.90
/PET8_P: J1.B50, J2.92
/PET9_N: J1.B55, J2.84
/PET9_P: J1.B54, J2.86
/PET10_N: J1.B59, J2.78
/PET10_P: J1.B58, J2.80
/PET11_N: J1.B63, J2.72
/PET11_P: J1.B62, J2.74
/PET12_N: J1.B67, J2.66
/PET12_P: J1.B66, J2.68
/PET13_N: J1.B71, J2.60
/PET13_P: J1.B70, J2.62
/PET14_N: J1.B75, J2.54
/PET14_P: J1.B74, J2.56
/PET15_N: J1.B79, J2.48
/PET15_P: J1.B78, J2.50
/REFCLK_N: J1.A14, J2.153
/REFCLK_P: J1.A13, J2.155
/SMCLK: J1.B5, J2.34
/SMDAT: J1.B6, J2.32
/TH_OVERT#: J2.20, Q1.1
/TMDS_HPD: J2.31, J8.19
/TMDS_SCL: J2.35, J8.15
/TMDS_SDA: J2.33, J8.16
/WAKE: J1.B11, J2.4
CEC: J2.29, J8.13
GND: J1.A4, J1.A12, J1.A15, J1.A18, J1.A20, J1.A23, J1.A24, J1.A27, J1.A28, J1.A31, J1.A34, J1.A37, J1.A38, J1.A41, J1.A42, J1.A45, J1.A46, J1.A49, J1.A51, J1.A54, J1.A55, J1.A58, J1.A59, J1.A62, J1.A63, J1.A66, J1.A67, J1.A70, J1.A71, J1.A74, J1.A75, J1.A78, J1.A79, J1.A82, J1.B4, J1.B7, J1.B13, J1.B16, J1.B18, J1.B21, J1.B22, J1.B25, J1.B26, J1.B29, J1.B32, J1.B35, J1.B36, J1.B39, J1.B40, J1.B43, J1.B44, J1.B47, J1.B49, J1.B52, J1.B53, J1.B56, J1.B57, J1.B60, J1.B61, J1.B64, J1.B65, J1.B68, J1.B69, J1.B72, J1.B73, J1.B76, J1.B77, J1.B80, J2.11, J2.13, J2.15, J2.17, J2.36, J2.37, J2.46, J2.47, J2.52, J2.53, J2.58, J2.59, J2.64, J2.65, J2.70, J2.71, J2.76, J2.77, J2.82, J2.83, J2.88, J2.89, J2.94, J2.95, J2.100, J2.101, J2.106, J2.107, J2.112, J2.113, J2.118, J2.119, J2.124, J2.125, J2.133, J2.134, J2.139, J2.140, J2.145, J2.146, J2.151, J2.152, J2.157, J2.166, J2.173, J2.174, J2.179, J2.180, J2.185, J2.186, J2.191, J2.192, J2.197, J2.198, J2.203, J2.204, J2.209, J2.210, J2.215, J2.216, J2.221, J2.222, J2.228, J2.244, J2.250, J2.251, J2.256, J2.257, J2.262, J2.263, J2.268, J2.269, J2.275, J2.E3, J2.E4, J3.5, J3.6, J3.7, J3.8, J4.2, J4.5, J4.8, J4.11, J4.16, J4.19, J4.S1, J4.S2, J4.S3, J4.S4, J5.1, J8.2, J8.5, J8.8, J8.11, J8.17, J8.MH1, J8.MH2, J8.MH3, J8.MH4, MH1.1, MH2.1, MH3.1, MH4.1, U1.1
unnamed: D1.1, D1#2.1, U1.3
unnamed: D5.1, D5#2.1
unnamed: D5.2, D5#2.2, U1.2
unnamed: D7.1, J5.2
unnamed: FB1.1, J2.164
unnamed: FB2.1, J2.162
unnamed: FB3.1, J2.172
unnamed: FB4.1, J2.170
unnamed: FB5.2, J2.168
unnamed: J1.A1, J1.B17, J1.B31, J1.B48, J1.B81
TH_PWM: J2.24, J5.4

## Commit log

2021-02-22 Added initial build version 1.0
    [PCIEx1toMXM3.0.dsn, PCIEx1toMXM3.0.kicad_pcb, PCIEx1toMXM3.0.sch]
2021-02-23 Fixed minor issues
    [PCIEx1toMXM3.0.kicad_pcb, PCIEx1toMXM3.0.sch]
2021-02-23 Reupload Files
    [PCIEx1toMXM3.0.kicad_pcb, PCIEx1toMXM3.0.sch]
2021-02-27 Added license
    [AltiumPCIEx1toMXM.PrjPcb, PCB1.PcbDoc, PCIEx16toMXM3.0 (1).kicad_pcb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]
2021-02-27 Added x16 base files
    [AltiumPCIEx1toMXM.PrjPcb, PCB1.PcbDoc, PCIEx16toMXM3.0.kicad_pcb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]
2021-03-03 Added x16 prototype
    [PCIEx16toMXM3.0.kicad_pcb]
2021-03-03 Started work on x16 adapter
    [PCIEx16toMXM3.0.kicad_pcb, PCIEx16toMXM3.0.sch]
2021-03-04 Made progress on PCIE x16 adapter
    [PCIEx16toMXM3.0.PcbDoc, PCIEx16toMXM3.0.PrjPcb, PCIEx16toMXM3.0.SchDoc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]
2021-03-06 Updated parts
    [PCIEx16toMXM3.0 Mini.kicad_pcb, PCIEx16toMXM3.0 Mini.sch, PCIEx16toMXM3.0.PcbDoc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]
2021-03-08 Made some changes
    [PCIEx16toMXM3.0 Mini.kicad_pcb, PCIEx16toMXM3.0.kicad_pcb]
2021-03-30 Made some changes and added new Altium documents
    [CON_PCI_Express_X16_164PIN.SchDoc, CON_PCI_Express_X1_36PIN.SchDoc, Molex_45586-8-Pin-PWR.PrjPcb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]
2021-04-01 Updated gitignore
    [(KiCAD Old) PCIEx1toMXM3.0.PcbDoc, CON_PCI_Express_X1_36PIN.SchDoc, PCI Express_16765X11115_36PIN_Half length.PrjPCB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]
2021-04-23 Began transition to Altium.
    [CON_PCI_Express_X16_164PIN.SchDoc, Molex_45586-8-Pin-PWR.PrjPcb, PCI Express_24130X11115_164PIN.schdoc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]
2021-04-24 Basic dimensions of the x1 adapter made.
    [(KiCAD Old) PCIEx1toMXM3.0.PcbDoc, PCIE x1 MXM 3.1 Riser Basic.PCBDOC, PCIEx1toMXM3.0.PrjPcb]
2021-04-25 Worked on the designs.
    [(KiCAD Old) PCIE x1 MXM 3.1 Riser Basic.SchDoc, (KiCAD Old) PCIEx1toMXM3.0.PcbDoc, Bill of Materials.SchDoc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]
2021-04-26 Done some work on the adapters.
    [MXM 3.1 Connector Interface.SchDoc, PCIE to MXM Riser Basic.PrjPcb, PCIE x1 Edge Connector Interface.SchDoc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]
2021-04-26 Fixed 3.3V pin.
2021-04-27 Add 5V rail and other improvements.
    [(KiCAD Old) PCIEx1toMXM3.0.PcbDoc, OdbCache.cfg, PCIE to MXM Riser Basic.PrjPcb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]
2021-04-28 Made a few improvements.
    [(KiCAD Old) PCIEx1toMXM3.0.PcbDoc, Bill of Materials.SchDoc, Block Diagram.SchDoc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]
2021-04-29 Attempting fix 2 for the repository.
    [45586-0005.PcbLib, CON_PCI_Express_X16_164PIN.SchDoc, Molex_45586-8-Pin-PWR.PrjPcb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]
2021-05-12 Uploading progress with unresolved errors.
    [Bill of Materials.SchDoc, Block Diagram.SchDoc, Display Interfaces.SchDoc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]
2021-05-31 Completed most circuits and switched to 4 layer PCB.
    [(KiCAD Old) PCIE x1 MXM 3.1 Riser Basic.SchDoc, (KiCAD Old) PCIEx1toMXM3.0.PcbDoc, Display Interfaces.SchDoc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]
2021-05-31 Added render of updated PCB.
2021-06-13 Updated +5V and improved some aspects of the design.
    [Bill of Materials.SchDoc, Block Diagram.SchDoc, Display Interfaces.SchDoc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]
2021-06-17 Reduced via count, improved +5V rail, and other parts of the design.
    [PCIE to MXM Riser Basic.PrjPcb, Power Sources and Supply.SchDoc]
2021-06-20 Fixed some design rules and copper pours.
    [MXM 3.1 Connector Interface.SchDoc, PCIE x1 Edge Connector Interface.SchDoc]
2021-07-07 Added testpoints, working towards finalizing PCB design.
    [PCIE to MXM Riser Basic.PrjPcb]
2021-08-01 Made minor improvements, enlarged some testpoints.
    [Block Diagram.SchDoc, MXM 3.1 Connector Interface.SchDoc, PCIE to MXM Riser Basic.PrjPcb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]
2021-08-23 Improved overall layout and reworked power delivery.
    [MXM 3.1 Connector Interface.SchDoc, Power Sources and Supply.SchDoc]
2021-11-07 Cleaned up layout more, added +12V protection circuit to schematics.
    [PCIE x1 Edge Connector Interface.SchDoc, Power Sources and Supply.SchDoc]
2022-01-23 Made improvements to power delivery, added current limiter.
    [MXM 3.1 Connector Interface.SchDoc, Miscellaneous.SchDoc, PCIE to MXM Riser Basic.PrjPcb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]
2022-01-24 Added bypass capacitors, cleaned up schematics.
    [Bill of Materials.SchDoc, Block Diagram.SchDoc, Display Interface.SchDoc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]
2022-09-19 Uploaded prototype info and pending changes of the adapter.
    [Display Interface.SchDoc, PCIE to MXM Riser Basic.PrjPcb, Power Sources and Supply.SchDoc]
